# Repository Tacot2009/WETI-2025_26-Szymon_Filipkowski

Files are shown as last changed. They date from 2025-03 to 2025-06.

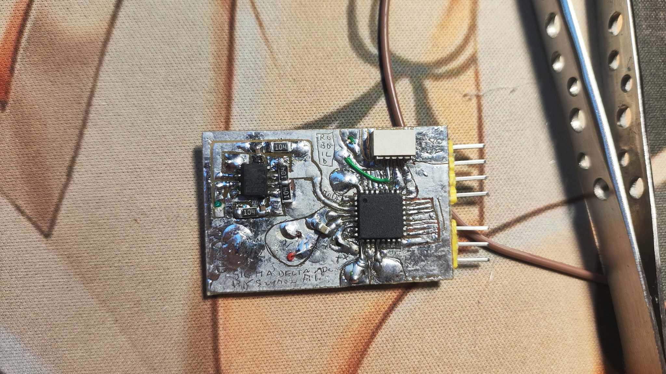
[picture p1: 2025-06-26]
.no-git_prezentacja/adc/504489837_1500150814921465_3774108829653451332_n.jpg

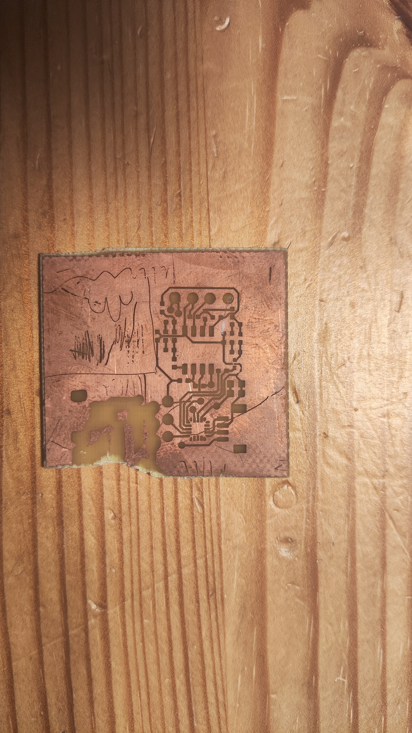
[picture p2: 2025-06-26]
.no-git_prezentacja/adc/IMG_20250626_230750.jpg

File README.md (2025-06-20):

# Sigma-Delta ADC

## Autor
**Szymon Filipkowski**

Projekt zgłoszony w ramach konkursu **„Wygraj Indeks WETI”**, organizowanego przez **Wydział Elektroniki, Telekomunikacji i Informatyki Politechniki Gdańskiej**.

## Opis projektu

Celem projektu było zaprojektowanie przetwornika analogowo-cyfrowego (ADC) typu **Sigma-Delta** – nowoczesnego rozwiązania stosowanego w wielu zastosowaniach inżynierii elektronicznej, takich jak systemy pomiarowe, przetwarzanie dźwięku, czy urządzenia IoT.

Przetwornik Sigma-Delta pozwala na uzyskanie wysokiej dokładności konwersji przy stosunkowo prostym układzie sprzętowym, dzięki zastosowaniu nadpróbkowania i modulacji sigma-delta. W projekcie wykorzystano cyfrową symulację toru ADC oraz zasymulowano pracę modulatora wraz z podstawową filtracją sygnału.

## Główne założenia

- Zaprojektowanie podstawowego modelu modulatora sigma-delta
- Symulacja cyfrowa układu
- Przejrzysta struktura projektu, gotowa do dalszej rozbudowy oraz implementacji sprzętowej

## Dlaczego Sigma-Delta?

Metoda sigma-delta jest powszechnie stosowana w nowoczesnych przetwornikach ADC ze względu na:
- wysoką jakość sygnału wyjściowego
- odporność na zakłócenia
- możliwość implementacji w postaci układów cyfrowych
- możliwość osiągania bardzo wysokich częstotliwości raportowania

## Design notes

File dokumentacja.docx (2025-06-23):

SIGMA DELTA ADC MODULE

BY SZYMON FILIPKOWSKI

Dokumentacja obejmuje Sigma Delta ADC module autorstwa Szymona Filipkowskiego, wersja v2.0.1.Projekt dostępny na serwisie GITHUB: https://github.com/Tacot2009/WETI-2025_26-Szymon_Filipkowski

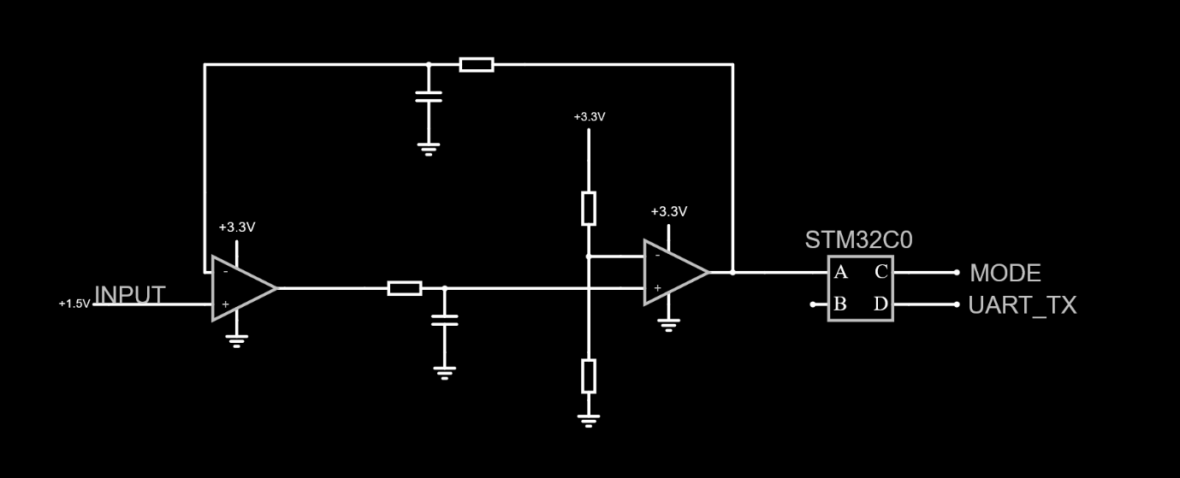
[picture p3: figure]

Kod źródłowy procesora:

https://github.com/Tacot2009/WETI-2025_26-Szymon_Filipkowski/blob/main/STM32-project/sigma-delta-adc-2/Core/Src/main.c

Schematy układu:

https://github.com/Tacot2009/WETI-2025_26-Szymon_Filipkowski/blob/main/Schemat/ADC.pdf

https://github.com/Tacot2009/WETI-2025_26-Szymon_Filipkowski/blob/main/Schemat/main.pdf

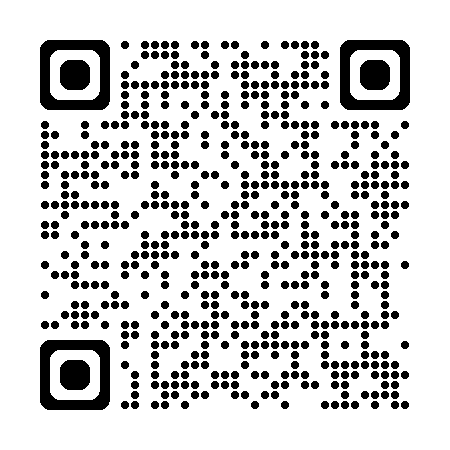
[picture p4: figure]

Kosztorys:

https://github.com/Tacot2009/WETI-2025_26-Szymon_Filipkowski/blob/main/lista-podzespolow-koszty.xlsx

Dokumentacja:

https://github.com/Tacot2009/WETI-2025_26-Szymon_Filipkowski/blob/main/dokumentacja.docx

link do strony projektu na serwisie github

Spis treści

1. Główne cechy
2. Przykładowe zastosowania
3. Opis
4. Historia wersji
5. Piny I/O i informacje o nich
6. Specyfikacja
a. Rekomendowane wartości pracy
b. Charakterystyka AC – tryb pojedyńczy
c. Charakterystyka AC – tryb ciągły
d. Absolutnie maksymalne wartości pracy
7. Dokładny opis
  a. Diagram
  b. Kontrola trybów pracy
  c. Opis działania
8. Informacje dodatkowe
1. Główne cechy
- Wbudowany procesor
- Zakres wejściowy 0V do 2.55V
- Zasilanie 3.3V
- Komunikacja jednostronna UART
- Łatwa zmiana trybów pracy
- Funkcjonalność plug-and-play
- Najażniejsze cechy
  - Rozdzielczość: 8 Bitów
  - Dokładność 0.01V
  - Częstotliwość raportowania 2Hz
  - Zużycie mocy ~10mW
  - Uart (baud 115200)
2. Przykładowe zastosowania
- Współpraca z dowolnym urządzeniem obsługującym protokół komunikacyjny UART.
- Interfejs do czujników temperatury, źródeł napięcia, przetworników, fotorezystorów itp.
3. Opis

„Sigma Delta ADC module by Szymon Filipkowski” to 8-bitowy przetwornik ADC wykorzystujący modulację Sigma-Delta do szacowania wartości cyfrowej sygnału wejściowego. Moduł wykorzystuje mikrokontroler z rodziny STM32C0 do dekodowania sygnału cyfrowego i przesyłania go w postaci wiadomości UART do urządzenia wyjściowego. Sprzęt i oprogramowanie są dostępne jako open-source na serwisie GITHUB, dzięki czemu każdy może dostosować ten moduł do własnych potrzeb. Autorem i twórcą projektu jest Szymon Filipkowski.

4. Historia wersji
- v1.0.0 - pierwszy projekt PCB, oprogramowanie w fazie rozwoju
- v1.2.0 – dodanie wyjścia obsługującego komunikację UART z procesora do głównego złącza wyjść na PCB, przewidziana do przyszłych zastosowań
- V.1.2.1 – dodanie dokumentacji w języku polskim
- v1.3.0 – dodano UART, dodano zlacze do programowania procesora
- v2.0.0 – nowy schemat, nowe pcb, uproszczenie układu, obniżenie ceny, optymalizacja kodu
- v2.0.1 – dodano README, dodano absolutnie maksymalne wartości pracy, dodano dodatkowe informacje, ogólne poprawki do dokumentacji
5. Piny I/O oraz informacje o nich

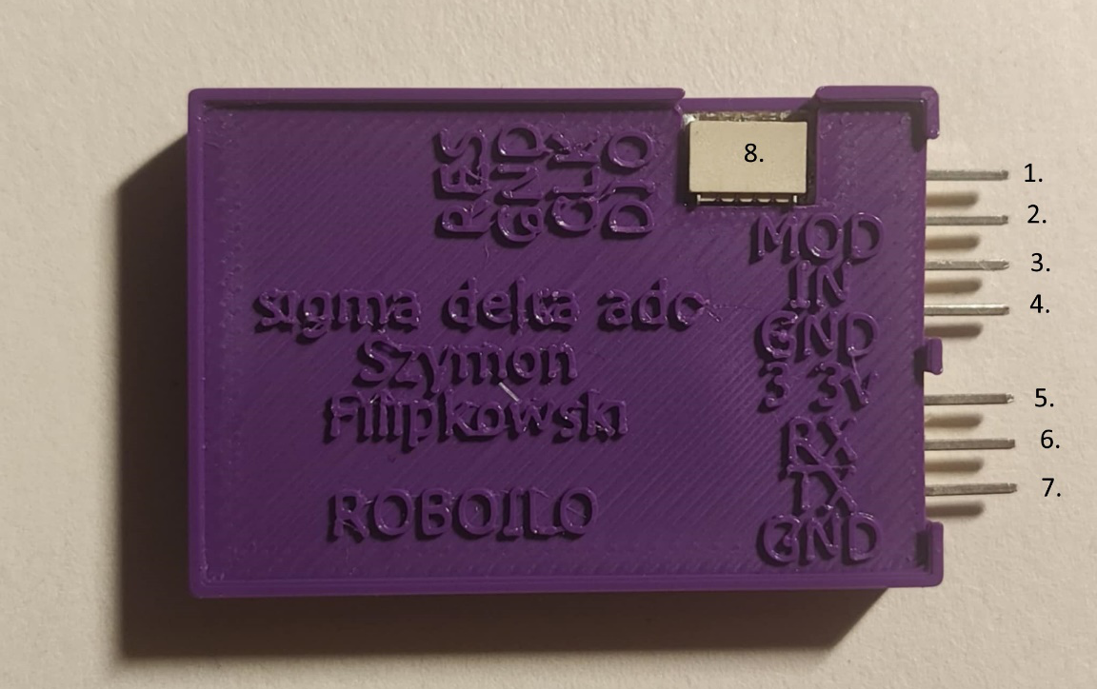
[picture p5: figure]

PIN | | I/O | DESCRIPTION
NO. | NAME
1. | MOD | I | Wybór trybu pracy
2. | IN | I | Wejście napięcia analogowego
3. | GND | I | Wejście masy (+0V)
4. | 3.3V (Vin) | I | Zasilanie +3.3V
5. | RX | I | Wejście danych protokołu UART (baud 115200)
6. | TX | O | Wyjście danych protokołu UART (baud 115200)
7. | GND | O | Referencja 0V
8. | ZŁĄCZE PROG | I/O | Złącze programatora do procesora od lewe: NRST, GND, SWCLK, SWDIO

6. Specyfikacja
  a. Rekomendowane wartości pracy

| MIN | MAX | | JEDNOSTKA
Vin | 3.3 | 3.3 | | V
GND | 0 | 0 | | V
IN (Wejście napięcia analogowego) | 0 | 2.56 | | V
MOD (tryb pracy) | 0 | | 3.3 | V

  b. Charakterystyka AC – tryb pojedyńczy

| ZAŁOŻENIA TESTU | TYPOWE
Czas pojedynczej konwersji | Vin = 3.3 V IN = 1.28 V | 1 SEC
Zużycie energii | Vin = 3.3 V IN = 1.28 V | 9 mW

  c. Charakterystyka AC – tryb ciągły

| ZAŁOŻENIA TESTU | TYPOWE
Czas pojedynczej konwersji | Vin = 3.3 V IN = 1.28 V | 0.5 SEC
Zużycie energii | Vin = 3.3 V IN = 1.28 V | 11 mW

  d. Absolutnie maksymalne wartości pracy

Przekroczenie wartości granicznych podanych poniżej może spowodować trwałe uszkodzenie urządzenia. Są to jedynie wartości graniczne obciążenia – nie należy zakładać, że urządzenie będzie działać poprawnie w tych warunkach. Długotrwałe narażenie na warunki graniczne może negatywnie wpłynąć na niezawodność urządzenia.

| MIN | MAX | | JEDNOSTKA
Vin - GND | -0.1 | 3.8 | | V
IN (Wejście napięcia analogowego) | 0 | Vin | | V
MOD (tryb pracy) | GND – 0.1 | | Vin + 0.1 | V

7. Dokładny opis
  a. Diagram
  b. Kontrola trybów pracy

Urządzenie ADC obsługuje dwa tryby pracy: tryb wywołania (tryb pojedynczy) i tryb ciągły (tryb automatyczny). Tryb automatyczny jest domyślnym trybem modułu. Aby użyć trybu pojedynczej konwersji należy zewrzeć pin MOD z GND (+0V) PRZED włączeniem modułu; następnie go włączyć. W tym trybie ADC wykonuje jedną konwersję napięcia i wysyła ją za pomocą protokołu UART. Następnie MCU przechodzi w tryb oszczędzania energii. Aby ponowić konwersję należy zmienić logiczny stan pinu MOD. Nie zaleca się wyłączania całego układu. Jeśli pin podczas włączenia układu pin MOD pozostał rozłączony - moduł działa w trybie automatycznym, przesyłając dane przez protokół UART po każdej zakończonej konwersji napięcia wejściowego.

  c. Opis działania
      1. Sygnał analogowy jest oczytywany bezpośrednio ze źródła.
      2. Wzmacniacz operacyjny w konfiguracji diffrence aplifier odejmuje napięcie sprzężenia zwrotnego od sygnału wejściowego. Tworzy to sygnał błędu pokazujący różnicę między wejściem a aktualnym wyjściem.
      3. Filtr dolnoprzepustowy działający jako integrator przetwarza sygnał błędu. Filtruje szum o wysokiej częstotliwości i wprowadza opóźnienie.
      4. Wzmacniacz operacyjny pełniący funkcję komparatora konwertuje zintegrowany sygnał na cyfrowe wyjście binarne. Powstałe wyjście cyfrowe służy zarówno jako wynik konwersji, jak i sprzężenie zwrotne dla ciągłej korekcji błędu.
      5. W między czasie co określoną ilość czasu procesor zlicza czas w który sygnał logicznym był wysokim i porównuje go do czasu całkowitego. Na podstawie tych danych przesyła obliczone napięcie wejściowe przez pin TX protokołem komunikacyjnym UART o baudzie 115200.
8. Informacje dodatkowe

Moduł został zaprojektowany w sposób umożliwiający elastyczne dostosowanie częstotliwości raportowania. W razie potrzeby można ją łatwo zwiększyć wyłącznie za pomocą zmian w oprogramowaniu, kosztem nieznacznego obniżenia dokładności przetwarzania. Takie podejście pozwala dostosować działanie modułu do konkretnych wymagań aplikacji – w zależności od priorytetu: szybkości odczytu lub precyzji pomiaru.

Wstępne testy wykazały, że udało się osiągnąć częstotliwość raportowania na poziomie 5 kHz przy dokładności około 0.03V.

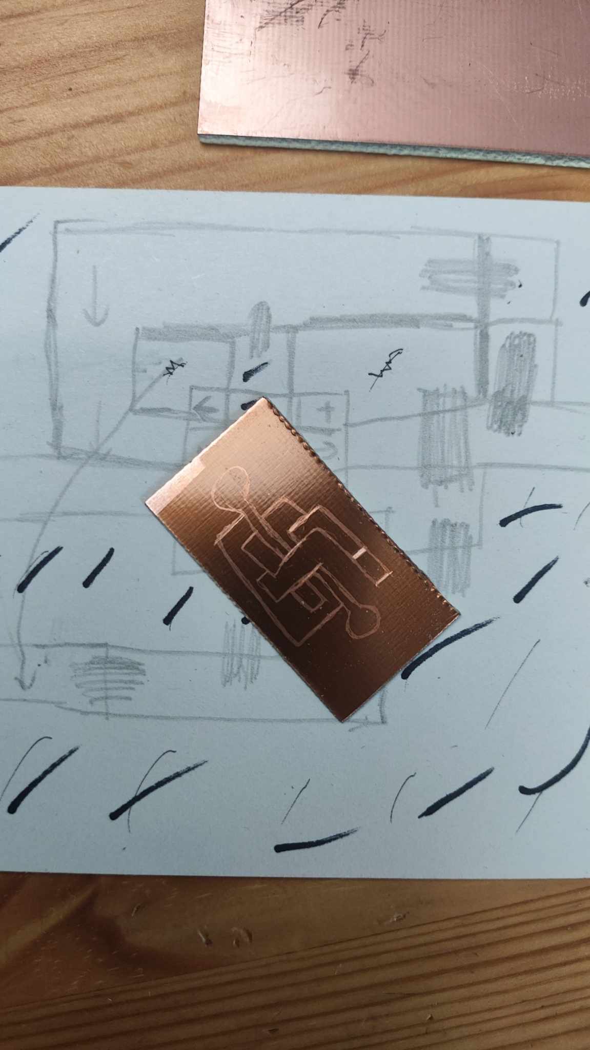
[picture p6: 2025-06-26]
.no-git_prezentacja/adc/503921210_704605459118837_6291065146912076543_n.jpg

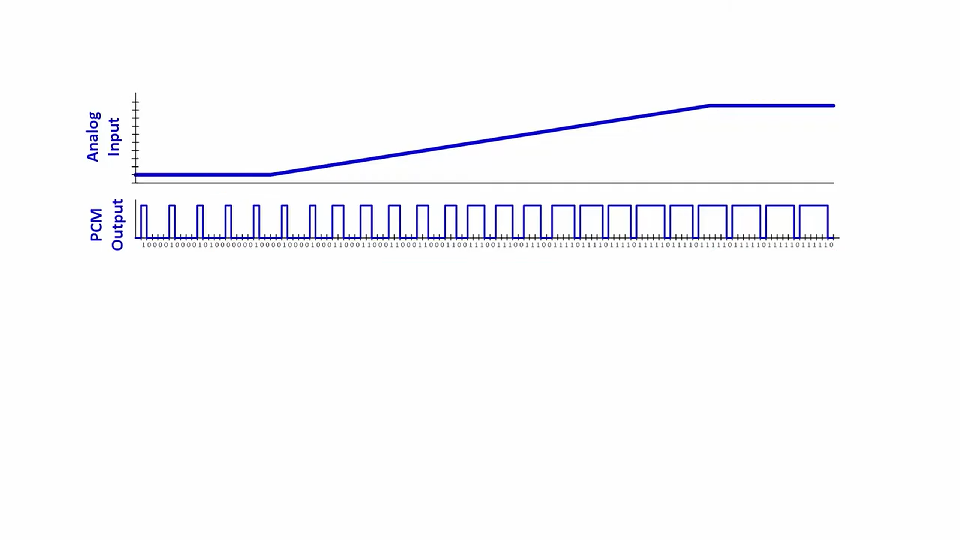
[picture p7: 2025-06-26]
.no-git_prezentacja/texas/Screenshot 2025-06-25 1810311.png

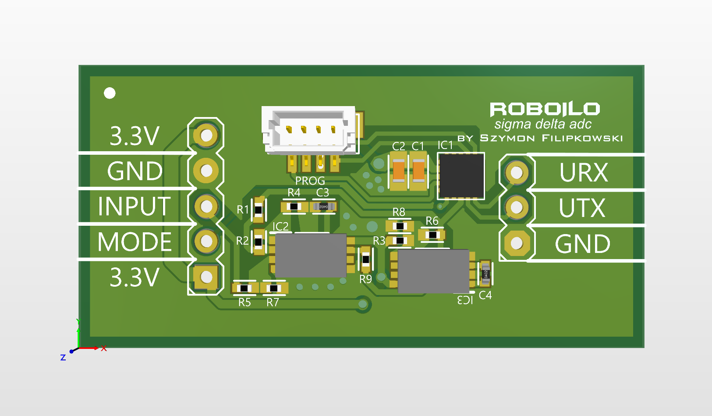
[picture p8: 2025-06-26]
.no-git_prezentacja/adc/Screenshot 2025-06-26 232137.png

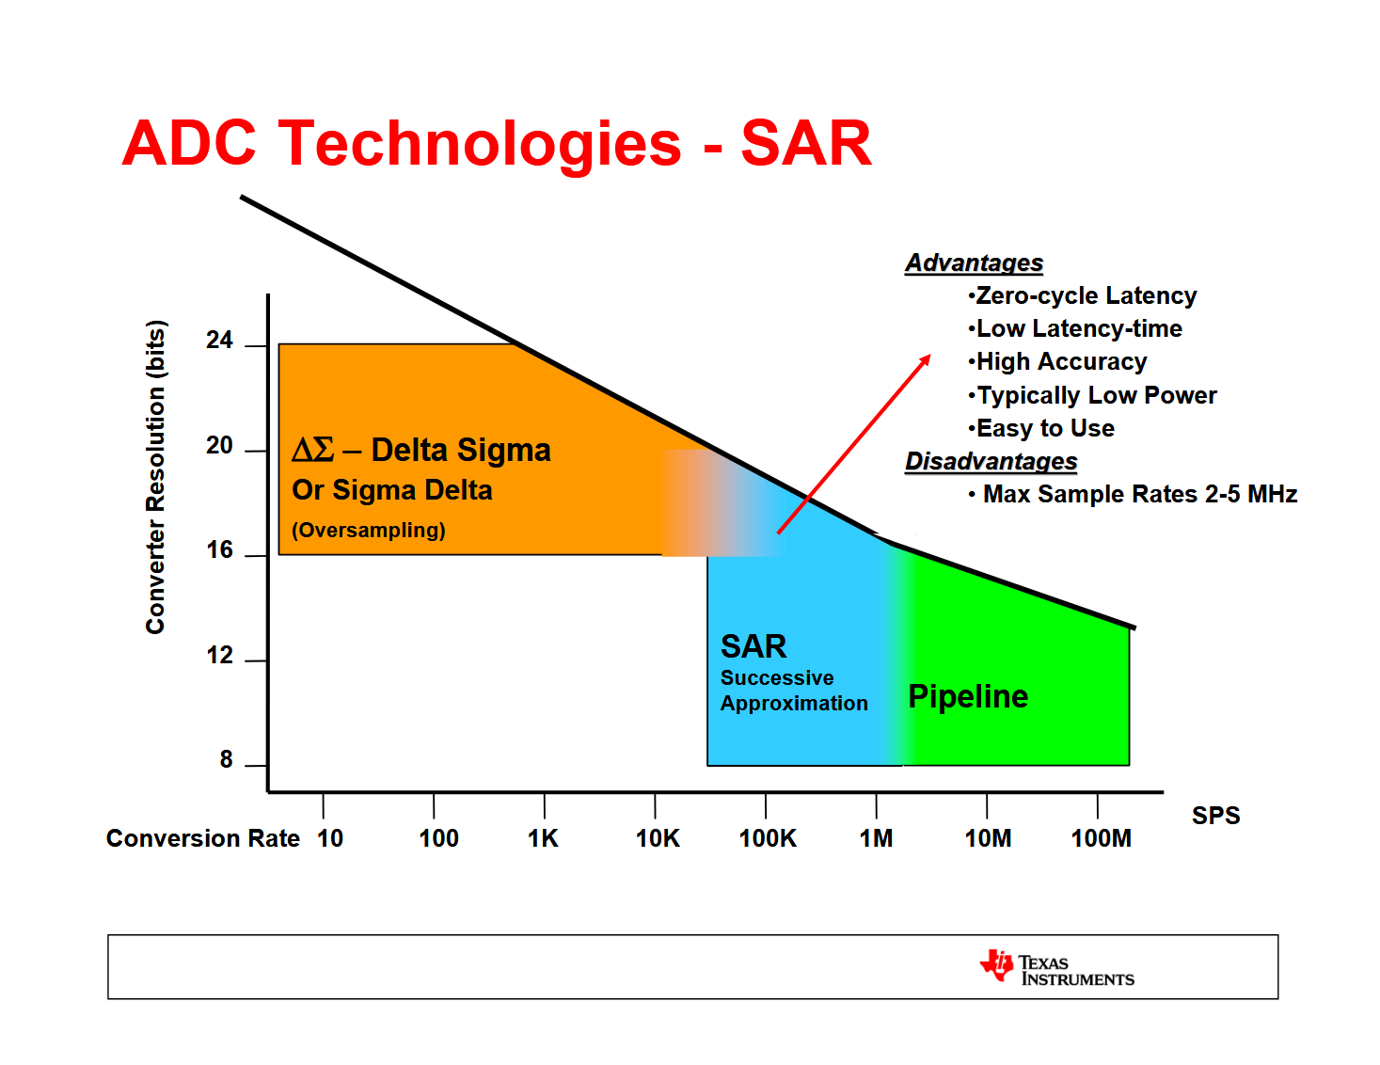
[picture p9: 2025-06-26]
.no-git_prezentacja/Screenshot 2025-06-26 211449.png

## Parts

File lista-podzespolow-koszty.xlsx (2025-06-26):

Description | Part comment | Quantity | Price per unit [PLN] | Value [PLN] | Comment | Link
MLCC Capacitor | 1uF | 1 | 0.15 | 0.15
MLCC Capacitor | 100nf | 2 | 0.15 | 0.30
Op-Amp | TLV2462CDGKR | 1 | 1.00 | 1.00 | https://www.digikey.pl/pl/products/detail/texas-instruments/TLV2462CDGKR/1677686
General pourpouse resistor | 100k | 4 | 0.15 | 0.60
Goldpin in 2.54mm raster | 5 PIN | 2 | 1.90 | 3.80 | https://botland.com.pl/akcesoria-do-raspberry-pi-pico/18854-zestaw-zlacz-meskich-do-gpio-raspberry-pi-pico-5904422328511.html
Central Procesing Unit | STM32C031 | 1 | 6.67 | 6.67 | https://pl.rs-online.com/web/p/mikrokontrolery/0214865?gb=s
PCB | - | 1 | 15.00 | 15.00
Full price per module [PLN] | 27.52

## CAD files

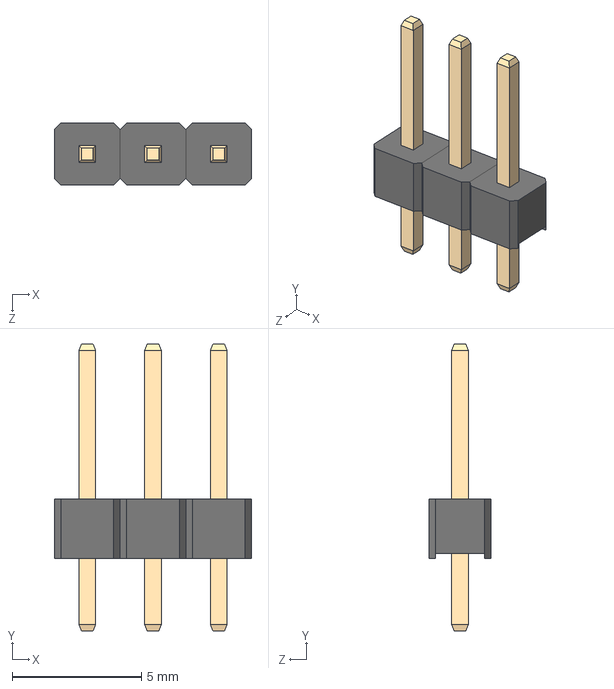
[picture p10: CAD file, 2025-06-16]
Inventor-project/3x_Male_Pin_2.54_mm.STEP
7.62 x 11.1 x 2.40 mm
1_Male_Pin_2.54_mm x 3

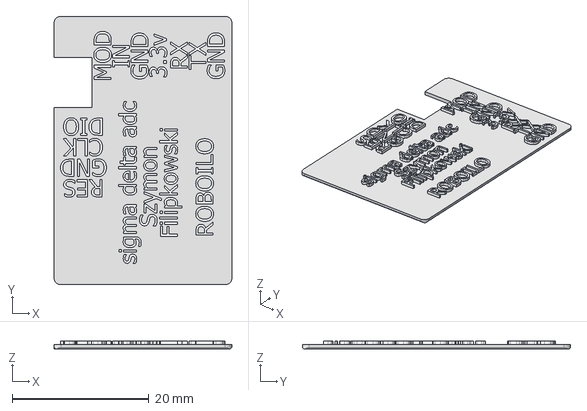
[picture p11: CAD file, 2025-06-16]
Inventor-project/ceil.stp
26.0 x 39.2 x 1.10 mm

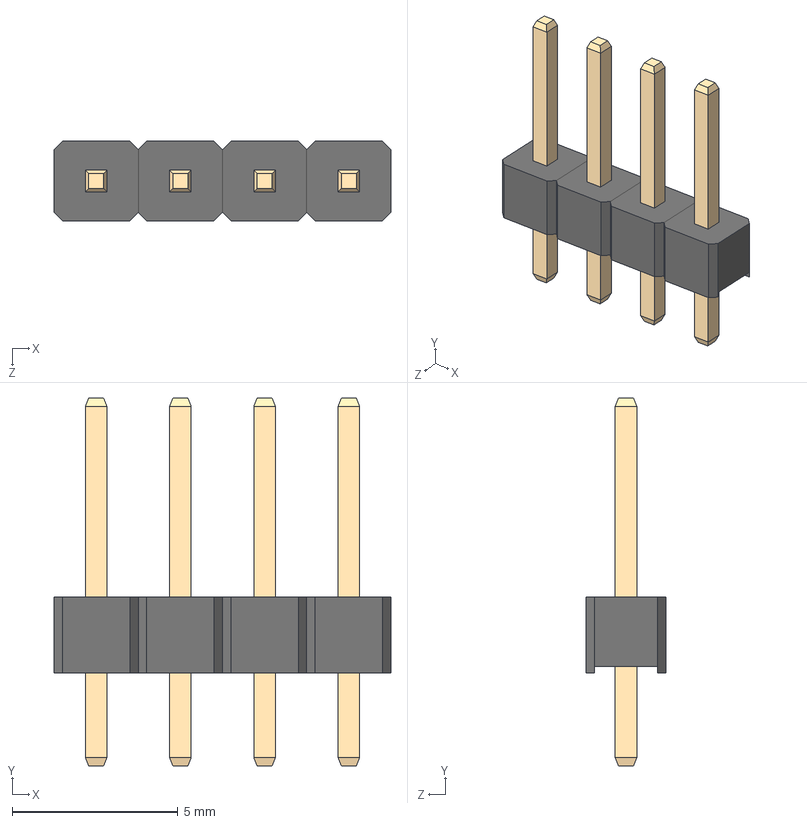
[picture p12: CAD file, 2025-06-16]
Inventor-project/4x_Male_Pin_2.54_mm.STEP
10.2 x 11.1 x 2.40 mm
1_Male_Pin_2.54_mm x 4

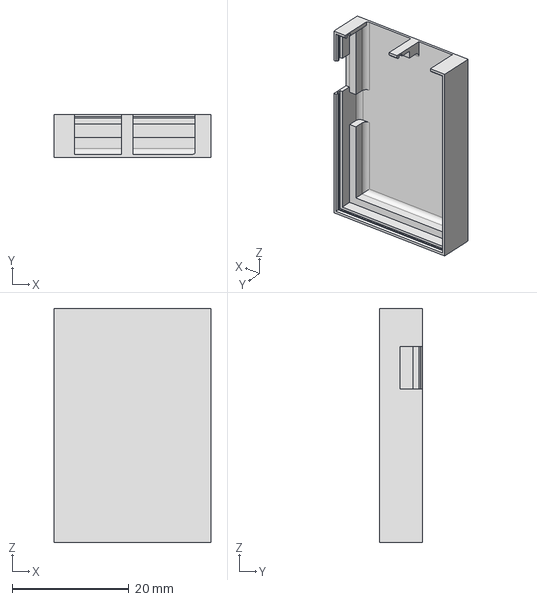
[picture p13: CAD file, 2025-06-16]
Inventor-project/case.stp
26.9 x 7.30 x 40.1 mm

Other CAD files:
Inventor-project/3x_Male_Pin_2.54_mm.ipt
Inventor-project/4x_Male_Pin_2.54_mm.ipt
Inventor-project/OldVersions/adc.0001.ipt
Inventor-project/OldVersions/case.0013.ipt
Inventor-project/OldVersions/ceil.0010.ipt
Inventor-project/OldVersions/main.0014.iam
Inventor-project/adc.ipt
Inventor-project/case.ipt
Inventor-project/ceil.ipt
Inventor-project/main.iam

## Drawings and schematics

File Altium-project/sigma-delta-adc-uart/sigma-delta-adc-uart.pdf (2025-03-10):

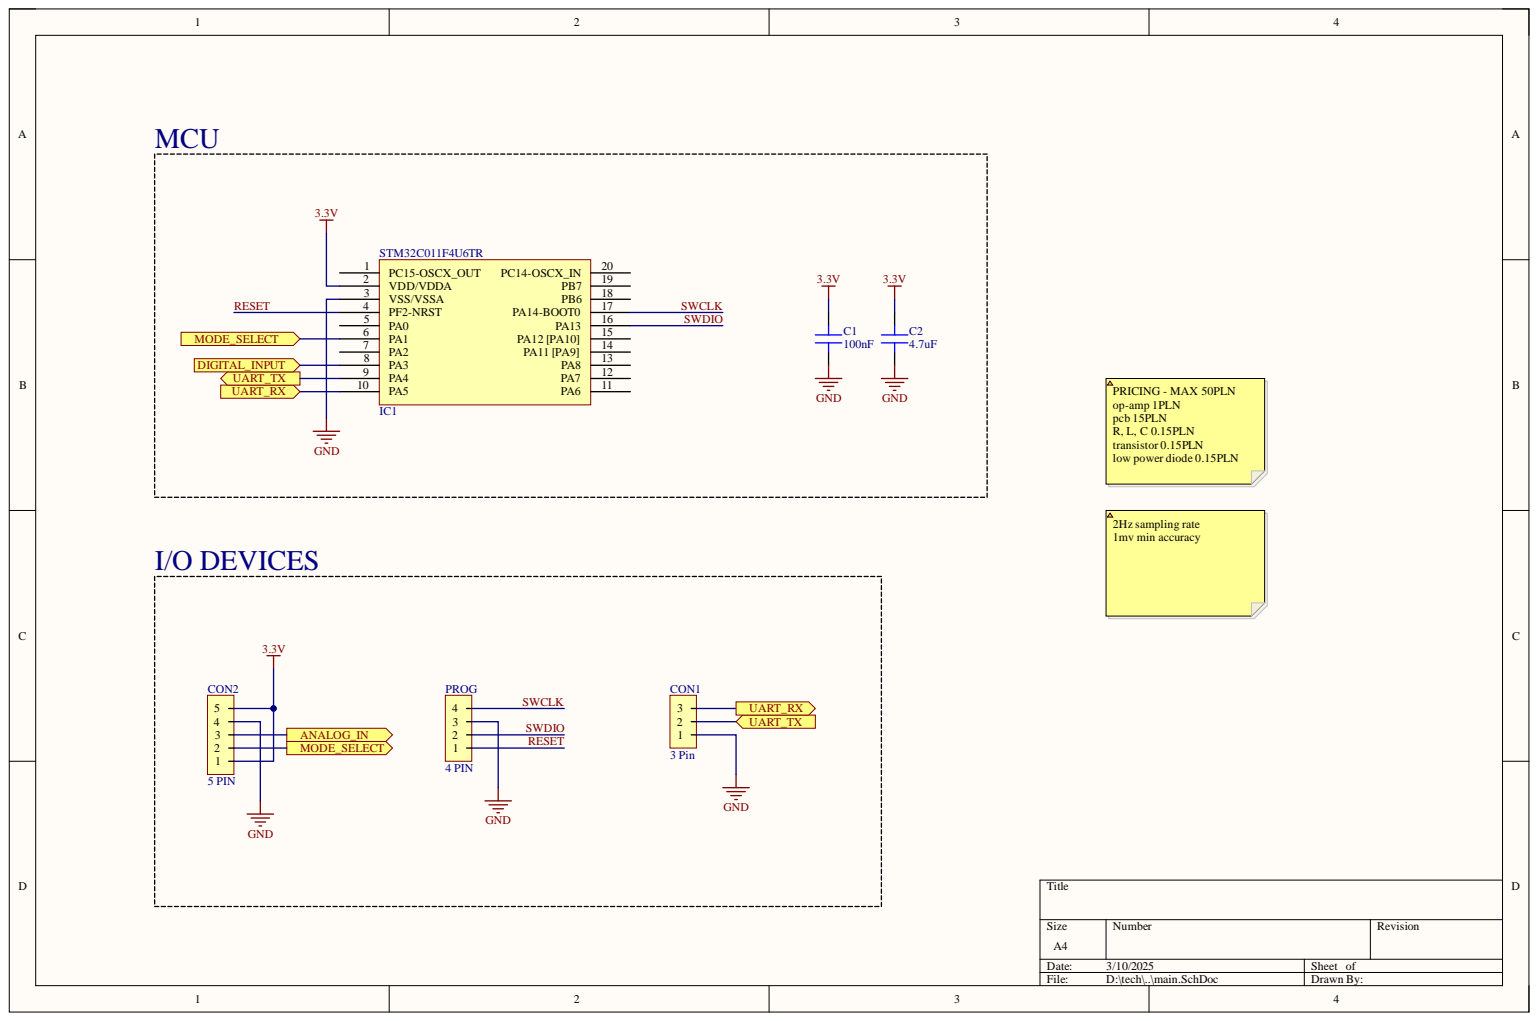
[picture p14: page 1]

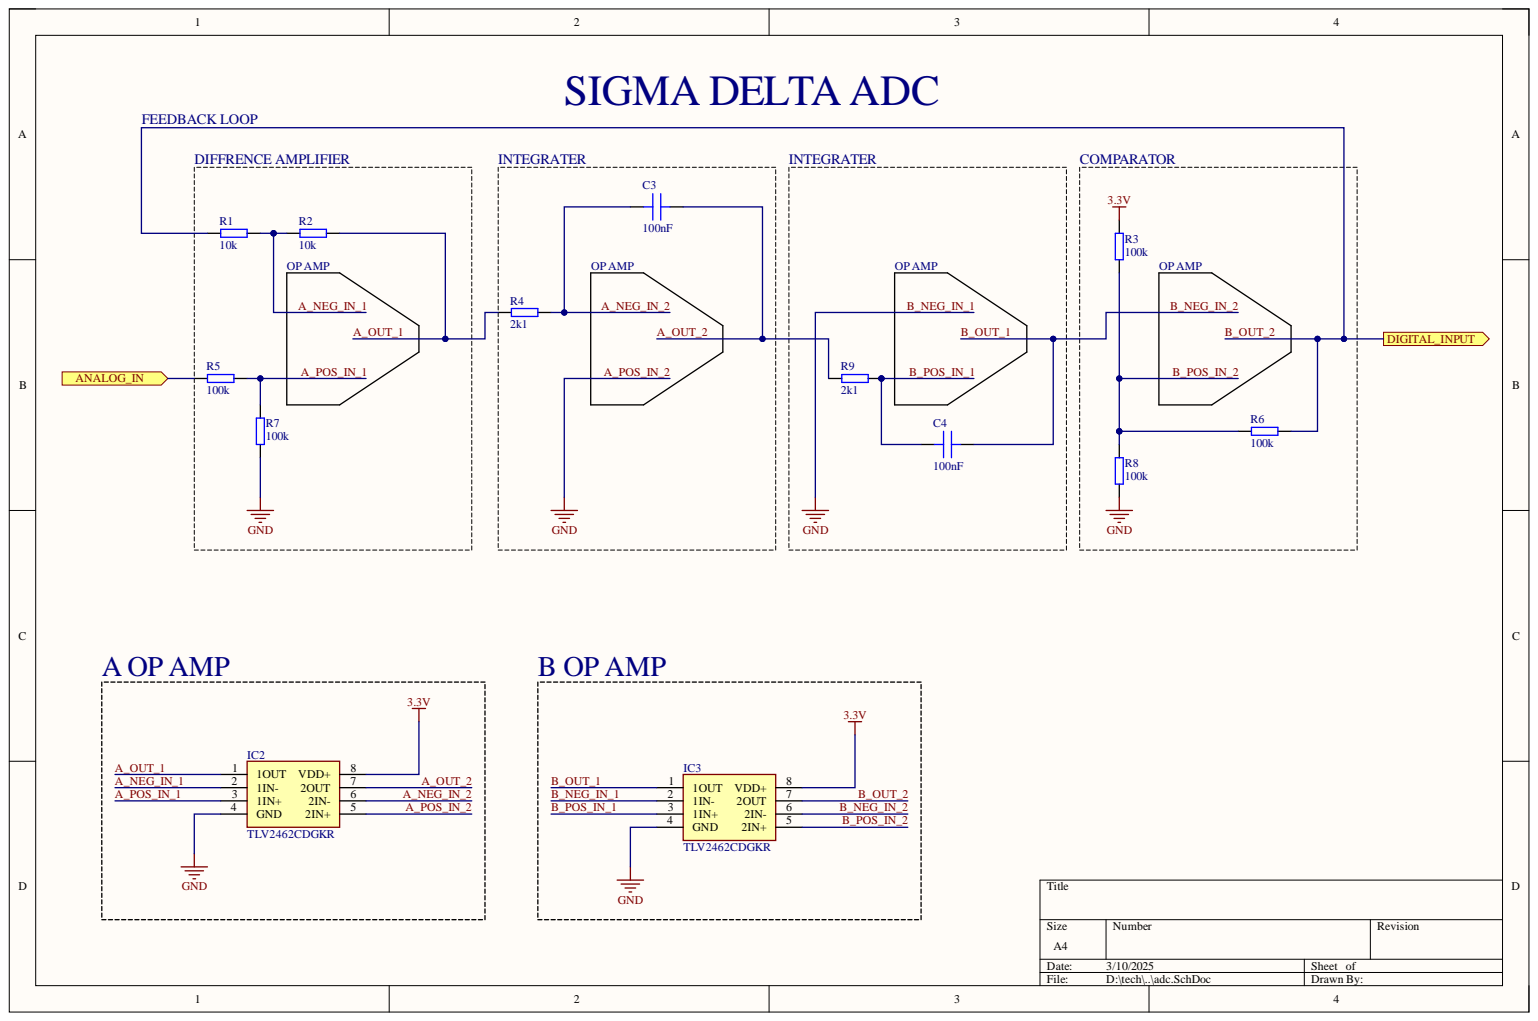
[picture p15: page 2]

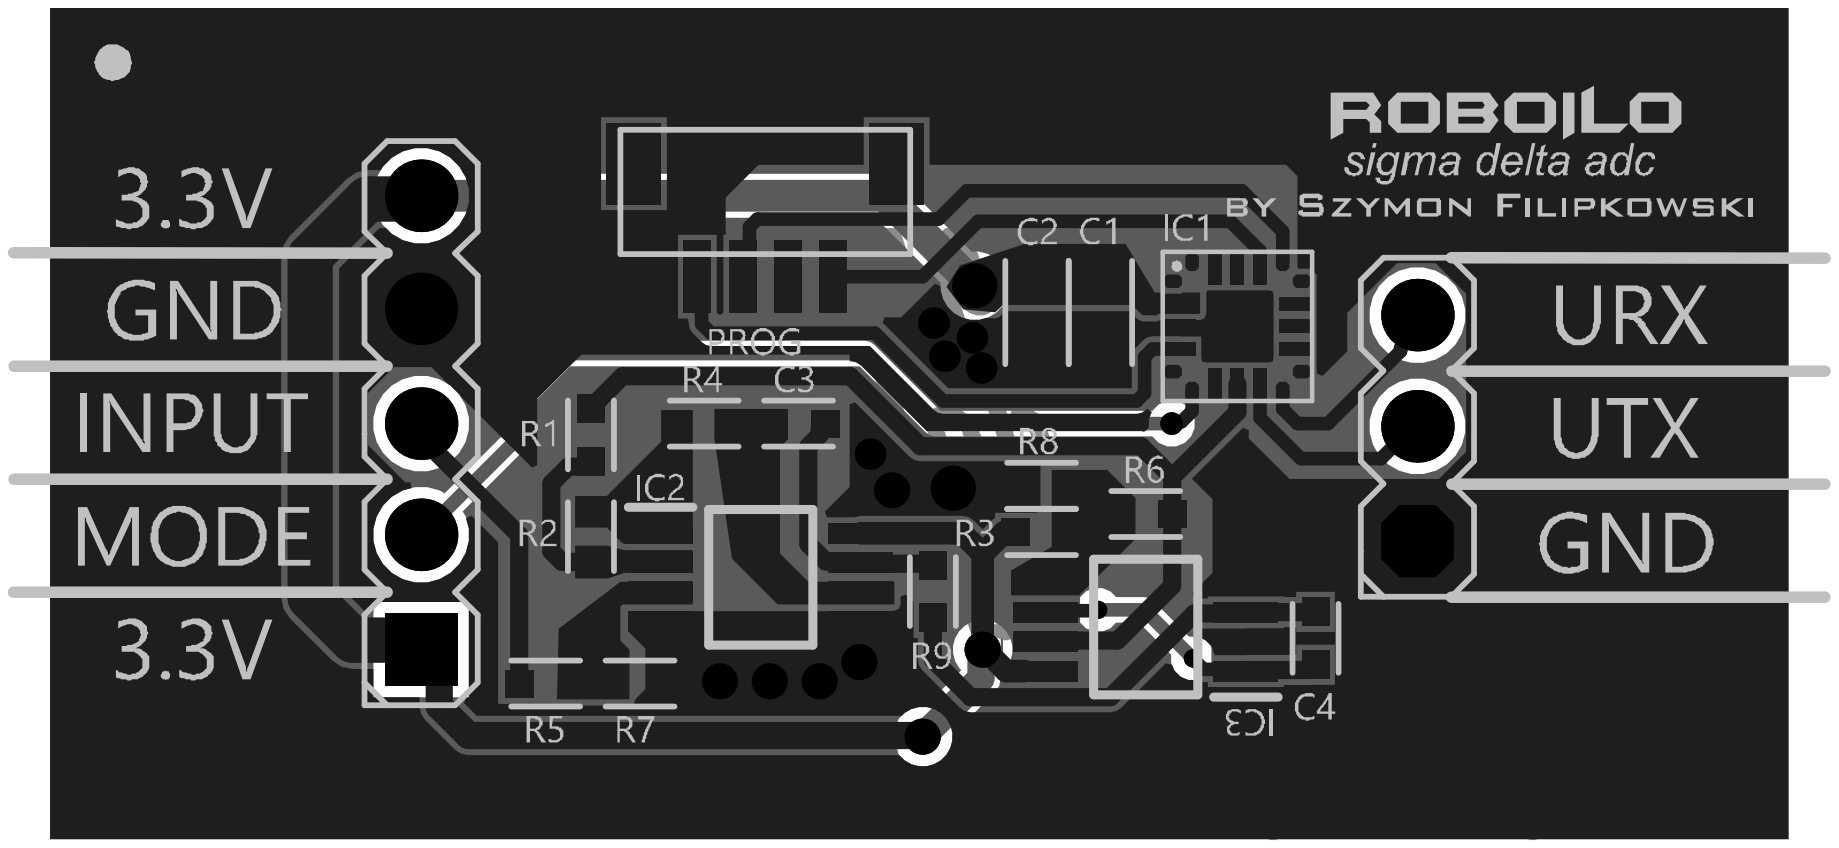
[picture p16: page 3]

Comment | Description | Designator | Footprint | LibRef | Quantity
100nF | MLCCCapacitor | C1 | C0603 | Capacitor | 1
4.7uF | MLCCCapacitor | C2 | C0603 | Capacitor | 1
100nF | MLCCCapacitor | C3, C4 | C0402 | Capacitor | 2
3Pin | | CON1 | Goldpin 2.54MM3P | 3Pin | 1
5PIN | | CON2 | Goldpin 2.54mm 5P | 5PIN | 1
STM32C011F4U6TR | | IC1 | UFQFPN20- byMe | STM32C011F4U6TR | 1
TLV2462CDGKR | Integrated Circuit | IC2, IC3 | SOP65P490X110-8N | TLV2462CDGKR | 2
4PIN | | PROG | BM04B-SRSS-TB | 4PIN | 1
10k | General pourpouse resistor | R1, R2 | R0402 | Resistor | 2
100k | General pourpouse resistor | R3, R5, R6, R7, R8 | R0402 | Resistor | 5
2k1 | General pourpouse resistor | R4, R9 | R0402 | Resistor | 2

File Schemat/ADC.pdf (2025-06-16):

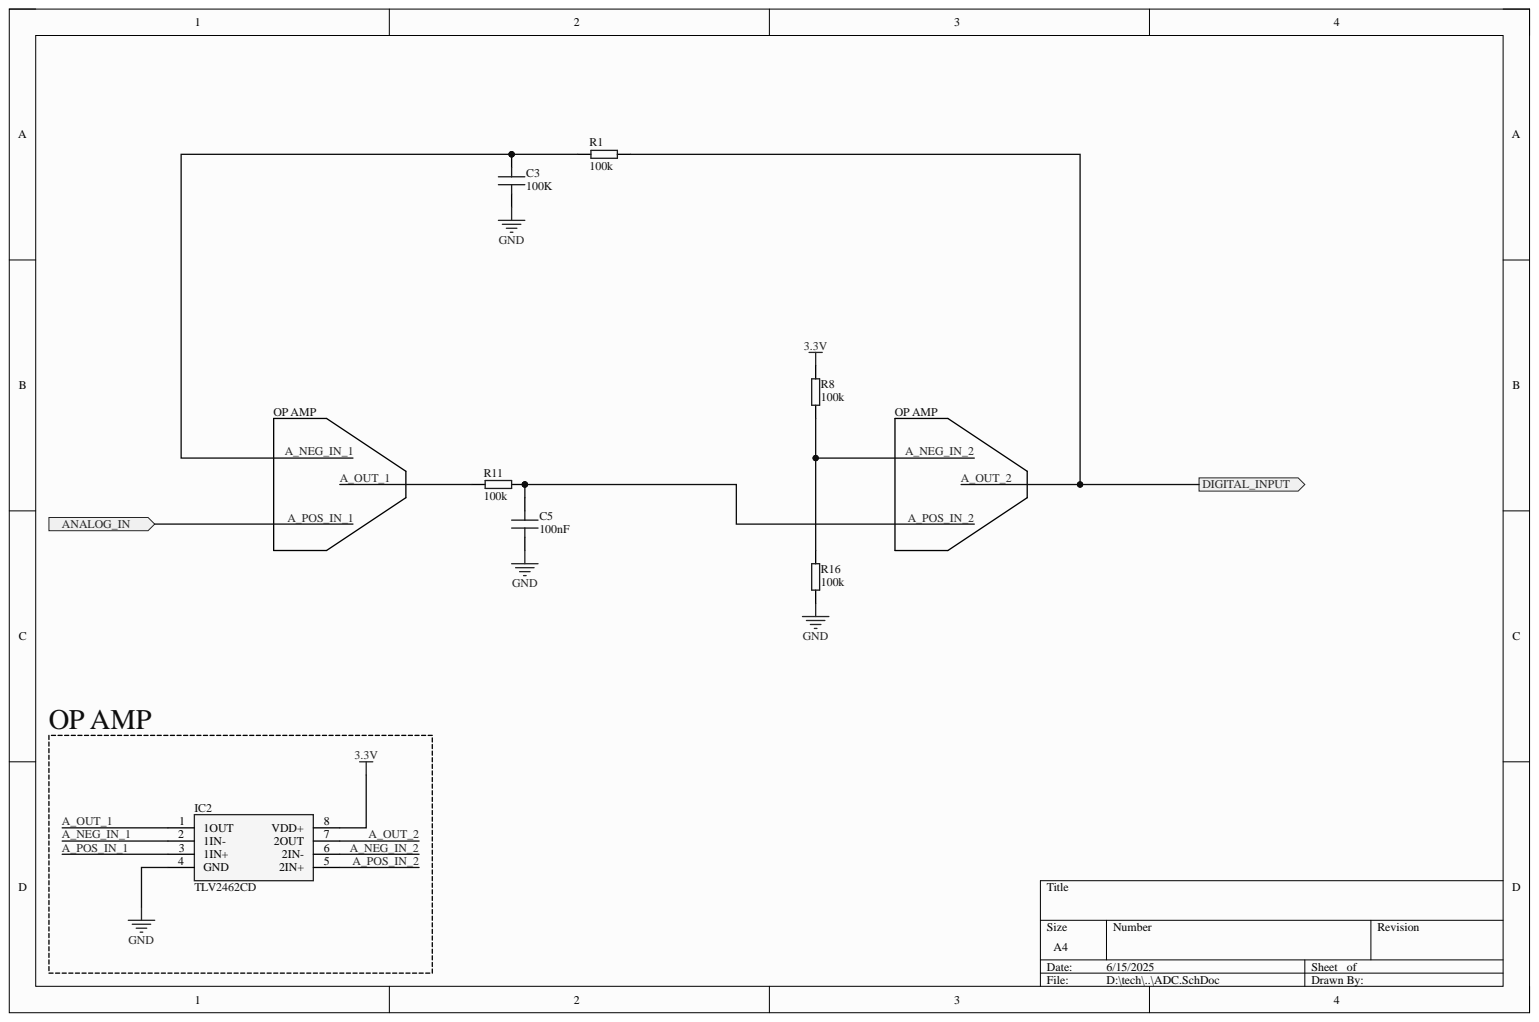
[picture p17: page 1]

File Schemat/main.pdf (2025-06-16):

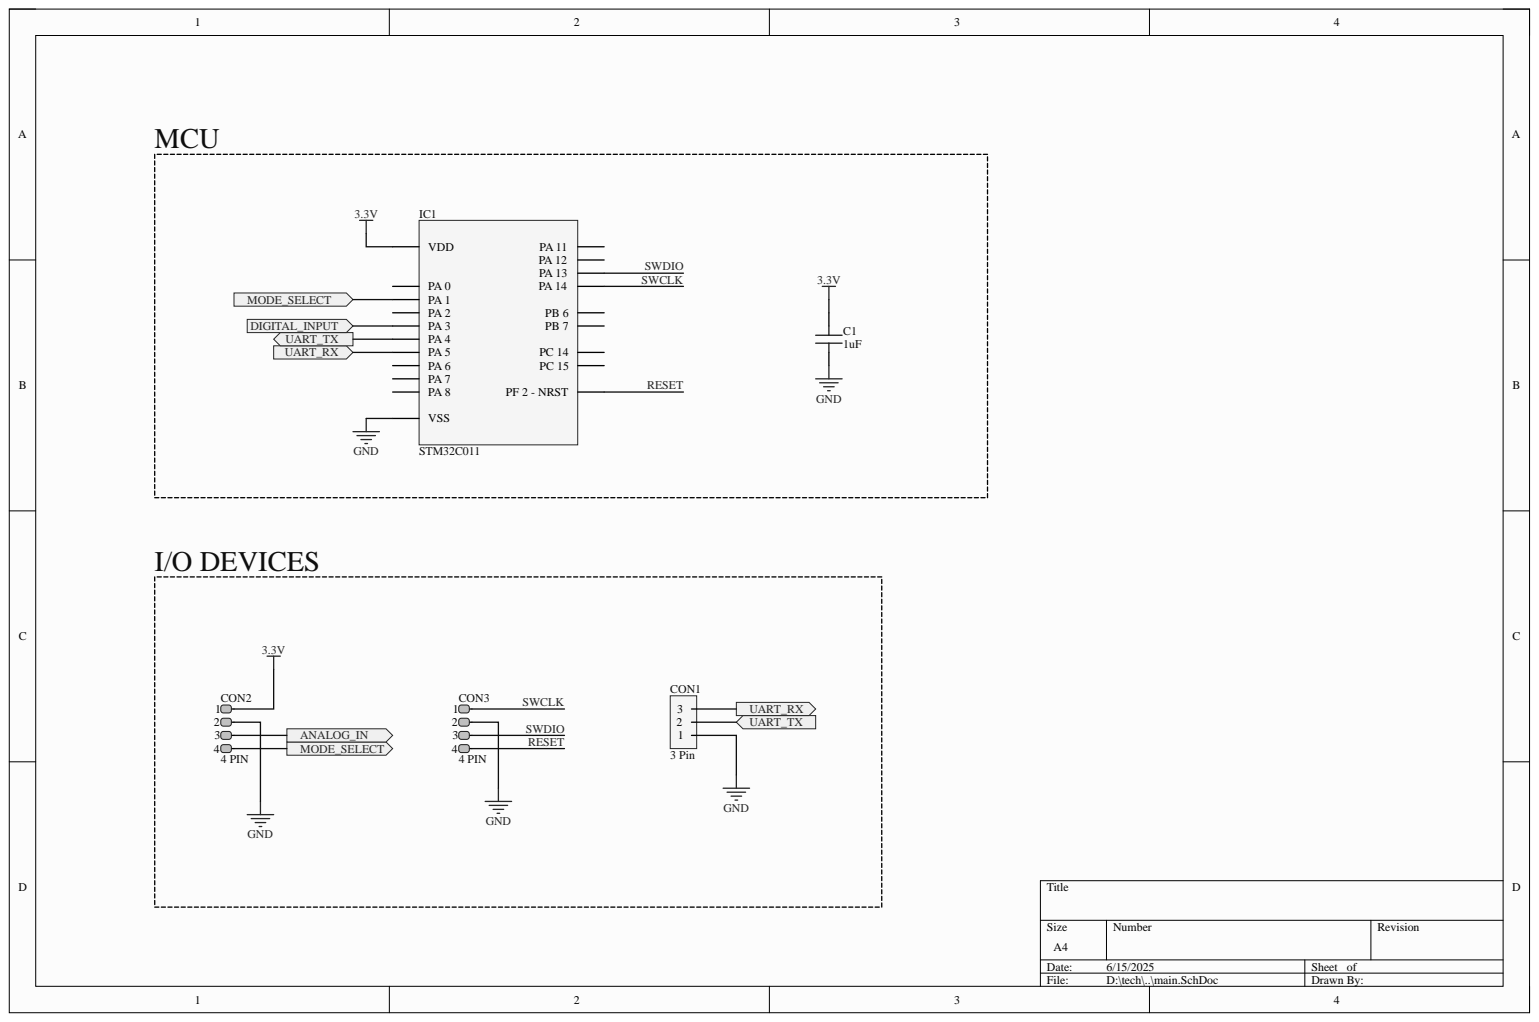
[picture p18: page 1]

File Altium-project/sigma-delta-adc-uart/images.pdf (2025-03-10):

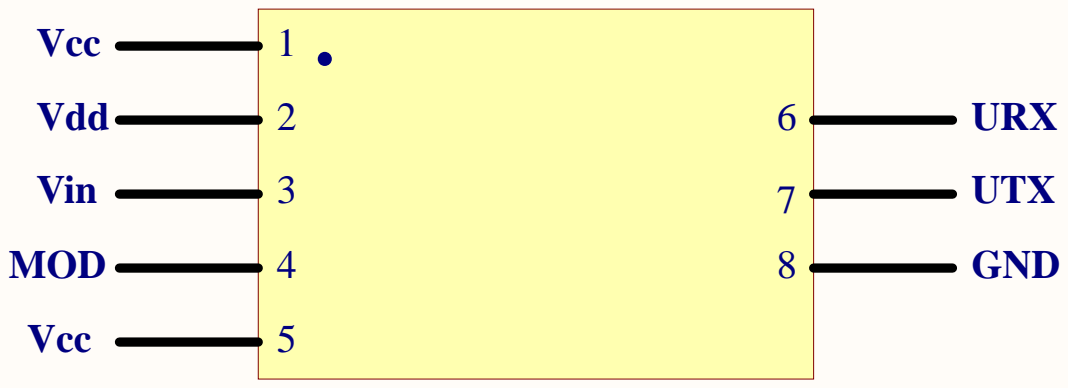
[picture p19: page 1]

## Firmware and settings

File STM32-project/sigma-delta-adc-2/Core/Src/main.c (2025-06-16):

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
/* Includes ------------------------------------------------------------------*/
#include "main.h"

/* USER CODE BEGIN PD */
//misc
#define true 1
#define false 0
#define HIGH 1
#define LOW 0
#define IDLE 0
#define STARTED 1
#define AUTO 0
#define SINGLE 1

//ADC settings
#define MULTIPLIER 0.03343
#define OFFSET 2.432

//Auto mode
#define BUFFER_SIZE 1 //uint16_t only; wielkosc buffera
#define MAX_TIMER_IDLE 490 //w MS; ile czasu poświęca na odczytywanie jednego napiecia
//BUFFER_SIZE * MAX_TIMER_IDLE = czas na stabilny odczyt

//Signle mode
#define TIMER_TIME_SINGLE 100 //time for calculation in signle mode
/* USER CODE END PD */


TIM_HandleTypeDef htim16;

UART_HandleTypeDef huart2;
DMA_HandleTypeDef hdma_usart2_tx;

/* USER CODE BEGIN PV */
//for output
uint16_t RAW_VOLTAGE = 255; //real voltage = VOLTAGE / 100  //TODO 8t
uint8_t VOLTAGE = 255; //real voltage = VOLTAGE / 100  //TODO 8t
uint32_t dupa=0;

uint16_t timer_OVC=0; //timer overrun counter

uint16_t MAX_TIMER_OVERRUNS;

uint32_t counter=0;
uint32_t counter_high=0;
uint16_t time0=0;
uint16_t ovc0=0;
uint8_t state = IDLE;
uint8_t workingMode = AUTO;
uint8_t singleWorkingState = IDLE;
/* USER CODE END PV */

void SystemClock_Config(void);
static void MX_GPIO_Init(void);
static void MX_DMA_Init(void);
static void MX_USART2_UART_Init(void);
static void MX_TIM16_Init(void);
/* USER CODE BEGIN PFP */
void ENABLE_DEEP_SLEEP(void);
void EXIT_DEEP_SLEEP(void);
void SEND_VIA_UART(void);
void CALCULATION_COMPLETED(void);
/* USER CODE END PFP */

/**
  * @brief  The application entry point.
  * @retval int
  */
int main(void)
{

  /* MCU Configuration--------------------------------------------------------*/

  /* Reset of all peripherals, Initializes the Flash interface and the Systick. */
  HAL_Init();

  /* Configure the system clock */
  SystemClock_Config();

  /* Initialize all configured peripherals */
  MX_GPIO_Init();
  MX_DMA_Init();
  MX_USART2_UART_Init();
  MX_TIM16_Init();
  /* USER CODE BEGIN 2 */
  HAL_Delay(10); //for sake of safety

  //check if mode is single
  if(HAL_GPIO_ReadPin(MODE_GPIO_Port, MODE_Pin) == 0) // single mode
  {
	  MAX_TIMER_OVERRUNS = (uint16_t)((TIMER_TIME_SINGLE / 1000.0f) / (((TIM16->PSC + 1.0f) * (TIM16->ARR + 1.0f)) / 48000000.0f));
	  counter = MAX_TIMER_OVERRUNS * (TIM16->PSC+1) * (TIM16->ARR+1);
	  workingMode = SINGLE;
	  singleWorkingState = STARTED;
  }
  else if(HAL_GPIO_ReadPin(MODE_GPIO_Port, MODE_Pin) == 1) // auto mode
  {
	  MAX_TIMER_OVERRUNS = (uint16_t)((MAX_TIMER_IDLE / 1000.0f) / (((TIM16->PSC + 1.0f) * (TIM16->ARR + 1.0f)) / 48000000.0f));
  	  counter = MAX_TIMER_OVERRUNS * (TIM16->PSC+1) * (TIM16->ARR+1);
  	  workingMode = AUTO;
  }
  //__HAL_RCC_PWR_CLK_ENABLE(); //stop mode config //TODO
  HAL_Delay(10); //for sake of safety

  HAL_TIM_Base_Start_IT(&htim16);
  /* USER CODE END 2 */

  /* Infinite loop */
  /* USER CODE BEGIN WHILE */
  while (1)
  {
    /* USER CODE END WHILE */

    /* USER CODE BEGIN 3 */
  }
  /* USER CODE END 3 */
}

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
/* USER CODE BEGIN 4 */
//====================================================================================================================================================================
//====================================================================================================================================================================
//====================================================================================================================================================================
/*	//TODO things
 * try to do digital read on EXTI???
deep sleep/light sleep cpu?
err show in console via uart?
*/

//nax lenght 1ms

//CCR3 - cos sie stalo
//CNT - clock counter

void HAL_GPIO_EXTI_Rising_Callback(uint16_t GPIO_Pin) //MODE pin was shorted with 3.3 => we are into manual mode
{
	if(GPIO_Pin == INPUT_Pin && state == IDLE && (workingMode == AUTO || singleWorkingState == STARTED))
	{
		time0 = TIM16->CNT;
		ovc0 = timer_OVC;
		state = STARTED;
	}

	if(GPIO_Pin == MODE_Pin && singleWorkingState == IDLE && workingMode == SINGLE)
	{
		EXIT_DEEP_SLEEP();
	}
}

void HAL_GPIO_EXTI_Falling_Callback(uint16_t GPIO_Pin) //MODE pin got release => we are going into auto mode
{
	if(GPIO_Pin == INPUT_Pin && state == STARTED && (workingMode == AUTO || singleWorkingState == STARTED))
	{
		counter_high = counter_high + (TIM16->CNT - time0) + (timer_OVC - ovc0)*TIM16->ARR;
		state = IDLE;
	}

	if(GPIO_Pin == MODE_Pin && singleWorkingState == IDLE && workingMode == SINGLE)
	{
		EXIT_DEEP_SLEEP();
	}

}

void HAL_TIM_PeriodElapsedCallback(TIM_HandleTypeDef* htim)
{
	if(htim->Instance == TIM16) //TIMER OVERFLOW
	{
		timer_OVC = timer_OVC + (workingMode == AUTO || singleWorkingState == STARTED);
		if(timer_OVC > MAX_TIMER_OVERRUNS) //every MAX_TIMER_IDLE run this
		{
			RAW_VOLTAGE=(uint32_t)(10000.0f*counter_high/counter); //raw but not voltage!

			counter_high=0;
			time0=0;
			timer_OVC=0;
			ovc0 = 0;
			state = IDLE;

			if(singleWorkingState == STARTED && workingMode == SINGLE)
			{
				singleWorkingState = IDLE;
			}

			CALCULATION_COMPLETED();
		}
	}
}

void CALCULATION_COMPLETED()
{
	//VOLTAGE
	int16_t v = MULTIPLIER*RAW_VOLTAGE+OFFSET;
	VOLTAGE = (v)*(v <= 255 && v >= 0) + (255)*(v > 255) + (0)*(v<0);
	SEND_VIA_UART(); //send info about readings via uart
}


void SEND_VIA_UART() //TODO //TODO //TODO
{
	static char uart_buffer[7];
    uart_buffer[0] = ((VOLTAGE / 100) % 10) + '0';
    uart_buffer[1] = '.';
    uart_buffer[2] = ((VOLTAGE / 10) % 10) + '0';
    uart_buffer[3] = (VOLTAGE % 10) + '0';
    uart_buffer[4] = 'v';
    uart_buffer[5] = '\r';
    uart_buffer[6] = '\n';

	if (huart2.gState == HAL_UART_STATE_READY)
	{
		HAL_UART_Transmit_DMA(&huart2, (uint8_t*)uart_buffer, 7);
	}
}


void HAL_UART_TxCpltCallback(UART_HandleTypeDef *huart)
{
    if(huart->Instance == USART2)
    {
		if(singleWorkingState == SINGLE) //go into deep sleep after uart if mode is single
		{
			singleWorkingState = IDLE;
			ENABLE_DEEP_SLEEP();
		}
    }
}

void ENABLE_DEEP_SLEEP() //on done calculations
{
	__HAL_DMA_DISABLE(&hdma_usart2_tx);
	HAL_UART_DeInit(&huart2);
	__HAL_RCC_USART2_CLK_DISABLE();

	HAL_TIM_Base_Stop_IT(&htim16);
	__HAL_RCC_TIM16_CLK_DISABLE();
	HAL_SuspendTick();

	//__HAL_RCC_PWR_CLK_ENABLE();
	//HAL_PWR_EnterSTOPMode(PWR_MAINREGULATOR_ON, PWR_STOPENTRY_WFI);
}

void EXIT_DEEP_SLEEP() //on falling edge
{
	singleWorkingState = STARTED;

	__HAL_RCC_TIM16_CLK_ENABLE();
	SystemClock_Config();
	HAL_ResumeTick();
	HAL_TIM_Base_Start_IT(&htim16);

	__HAL_RCC_USART2_CLK_ENABLE();
	MX_USART2_UART_Init();
	__HAL_DMA_ENABLE(&hdma_usart2_tx);
}
//====================================================================================================================================================================
//====================================================================================================================================================================
//====================================================================================================================================================================
/* USER CODE END 4 */
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


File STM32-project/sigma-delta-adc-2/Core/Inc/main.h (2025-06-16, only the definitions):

#define INPUT_Pin GPIO_PIN_15
#define INPUT_GPIO_Port GPIOC
#define INPUT_EXTI_IRQn EXTI4_15_IRQn
#define MODE_Pin GPIO_PIN_8
#define MODE_GPIO_Port GPIOB
#define MODE_EXTI_IRQn EXTI4_15_IRQn

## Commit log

2025-03-01 FULL PCB FIX
    [MCU.SchDoc, PCB1.PcbDoc, adc.SchDoc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]
2025-03-01 second itnegrater - in already used ic
    [PCB1.PcbDoc, adc.SchDoc]
2025-03-01 PCB and FALSTAD done!
2025-03-10 nnnn
    nnnnn
    [PCB1.PcbDoc, adc.SchDoc, images.SchDoc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]
2025-06-16 documentation update
    [odczyty-badania.xlsx, odczyty.xlsx]
2025-06-26 altium and prezentacja update
    [PCB1.PcbDoc, adc.SchDoc, images.SchDoc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]

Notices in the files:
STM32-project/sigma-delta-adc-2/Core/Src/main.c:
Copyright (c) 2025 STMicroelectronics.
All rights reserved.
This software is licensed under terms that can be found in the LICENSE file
